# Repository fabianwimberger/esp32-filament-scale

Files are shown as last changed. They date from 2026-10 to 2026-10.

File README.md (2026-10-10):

# ESP32 Filament Scale




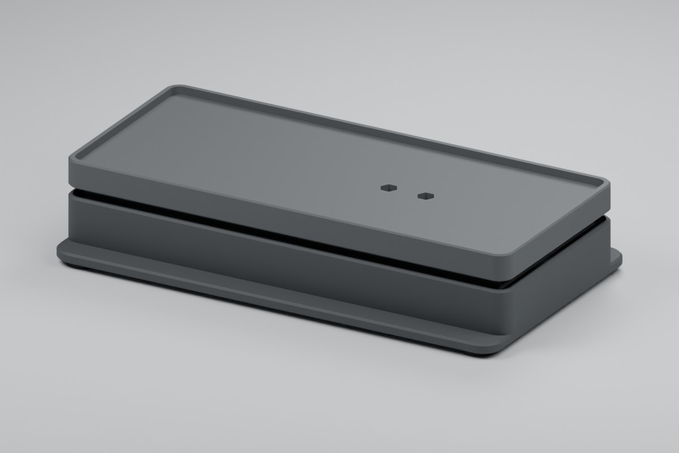
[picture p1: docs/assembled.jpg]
Assembled scale


Printed weighing plinth for a SUNLU S2 filament dryer. An ESP32-C3 and an HX711 report the filament left on the spool to Home Assistant through ESPHome.

## Background

A filament dryer hides the spool, so the only way to know whether a roll will last for the next print is to open the lid and guess. Weighing the whole dryer answers that without touching it: capture the weight once with a fresh spool inside, and everything that disappears afterwards is filament.

The scale is a 180 × 80 mm floating top on a 180 × 100 mm base, 34 mm tall, built around a cheap 5 kg bar load cell. It carries the S2's feet inside a low rim; the dryer's body overhangs it.

## Features

- **Filament remaining in grams and percent** — counts down from the mass of the spool you loaded
- **Calibration from Home Assistant** — three buttons: empty platform, known mass, dryer with full spool; no reflashing
- **Persistent calibration** — zero, gain and spool capture survive reboots and OTA updates; there is no startup tare
- **Stability gate** — a five-second window rejects captures while the reading moves and drops missing, stale or saturated samples
- **Four printed parts, M3 only** — base, top and two click-in board caps; four M3 × 20 screws clamp the cell
- **Parametric CAD** — one OpenSCAD file with assertions for every screw length and clearance
- **Diagnostics** — raw counts, noise range, saved calibration, chip temperature and Wi-Fi signal

## Quick Start

```bash
git clone https://github.com/fabianwimberger/esp32-filament-scale.git
cd esp32-filament-scale

python -m venv .venv
.venv/bin/pip install esphome

.venv/bin/esphome run firmware/scale.yaml   # first flash over USB
```

Join the **Filament Scale Setup** access point to enter your Wi-Fi, then add the discovered device in Home Assistant. Later updates go over the air:

```bash
.venv/bin/esphome run firmware/scale.yaml --device filament-scale.local
```

Print the four files in [`printable/`](printable/) and follow the [Build Guide](docs/build.md) for parts, wiring, assembly and calibration. The [Design Notes](docs/design.md) cover load path, clearances and limits.

To change the CAD:

```bash
make meshes   # export printable/*.stl from cad/scale.scad
make images   # re-render docs/ (OpenSCAD and Blender)
make check    # host tests, mesh checks, ESPHome config validation
```

## How It Works

```
dryer + spool ──► floating top ──► 5 kg bar cell ──► HX711 ──► ESP32-C3 ──► Home Assistant
                  (touches nothing    (fixed end        5 samples/s  5 s window    ESPHome API
                   but the cell)       on the base)

filament remaining = gross mass − (dryer + empty spool)
```

The cell is a cantilever: its cable end is clamped to a pedestal in the base, its free end to the top. Nothing else connects the two, so every gram on the top passes through the cell.

Calibration stores three values. **1 Capture empty platform** saves the zero, **2 Capture calibration mass** the counts per gram, and **3 Capture dryer with full spool** subtracts **Full filament mass** from the reading and saves the rest as dryer plus empty spool. Repeat step 3 for every new spool, because empty spools differ in weight.

Weight estimates use the median of the latest 25 samples to suppress brief filament pulls. Sustained load changes reach the estimate after about 2.6 seconds at the normal sample rate, then publish on the next five-second update. Zero and reference-mass captures still use the unfiltered average, and noise and stability diagnostics retain every sample. Updating this filter requires no recalibration and preserves the saved calibration and spool tare through a normal OTA update.

The design target is ±10 g. Cable tension, filament pull during a print, heat and plastic creep all shift the reading, so treat it as a trend while printing.

## Configuration

Substitutions at the top of `firmware/scale.yaml`:

| Variable | Default | Description |
|---|---|---|
| `device_name` | `filament-scale` | ESPHome node name / hostname |
| `friendly_name` | `Filament Scale` | Display name in Home Assistant |
| `dout_pin` | `GPIO4` | HX711 DT / DOUT |
| `clock_pin` | `GPIO3` | HX711 SCK / CLK |

The config ships without API encryption or an OTA password; add both before using it on a shared network.

Settings in Home Assistant:

| Entity | Default | Description |
|---|---|---|
| Full filament mass | 1000 g | Filament on the spool when step 3 is pressed |
| Calibration mass | 1000 g | Mass of the reference object used in step 2 |
| Calibration noise limit | 1000 counts | Largest raw range over five seconds that steps 1 and 2 accept |

Parameters at the top of `cad/scale.scad` adapt the print to other hardware:

| Variable | Default | Description |
|---|---|---|
| `platform_length`, `platform_width` | `180`, `80` | Top; the rim leaves 175 × 75 mm for the dryer's feet |
| `cell_hole_spacing`, `cell_hole_end` | `15`, `5` | Hole pattern of the 80 × 12.7 × 12.7 mm cell |
| `fixed_side` | `-1` | End of the cell that is clamped to the base |
| `esp32_pcb`, `hx711_pcb` | measured | Board sizes the pockets are cut for |
| `esp32_wire_zone` | `[3.6,14.4]` | Where the ESP32 cap is notched for wires, from the USB edge |

## License

MIT — see [LICENSE](LICENSE).

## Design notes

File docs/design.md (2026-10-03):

# Design Notes

Why the parts look the way they do, and what the design does not cover. Z positions are measured from the base floor and exclude the 2 mm pads.

## Load path

The dryer's feet stand on the top. A seat in the top's underside is clamped to the free end of the cell; the cable end of the cell is clamped to a pedestal in the base. That is the only connection between the two parts.

The load tips the pedestal towards the free end: its front edge presses down and its rear screw pulls up with about three times the load each, 19 mm apart. Two solid rails run beside the cell from behind the pedestal to the far end wall and spread that couple over 140 mm. Nothing stands under the cell, which has to bend freely.

## Clearances

| Clearance | Nominal |
|---|---:|
| Top above the base wall (the visible gap) | 3.5 mm |
| Top's underside inside the base walls | 4 mm |
| Top's underside above the base rails | 4 mm |
| Top's underside above the board caps | 6.9 mm |
| Cell above the base floor | 2.3 mm, 1.3 mm at the potting |
| Channel roof above the fixed-end screw tips | 4.2 mm |

Assertions in [`cad/scale.scad`](../cad/scale.scad) fail the export if a parameter change breaks one of these.

## Fastening

The cell's M4 and M5 threads are larger than M3, so every screw passes through the cell and clamps it with a nut.

- **Fixed end** — heads in counterbores under the base, 3.7 mm of printed seat, the cell, then washer and nut. The seat is as thick as a 20 mm screw allows, which leaves the heads 0.4 mm proud of the floor, inside the height of the pads.
- **Moving end** — head and washer under the cell, through the cell and 3.6 mm of solid seat into a nut at the bottom of a hex well open to the top face. The nut has to sit above the seat: a nut between seat and cell would be drawn onto the cell and leave the top loose.

The screws have about 1 mm of play in the cell's holes. Lips on the pedestal form a 13 mm slot that sets the cell's angle; the top's seat is flat and is squared by eye before tightening.

## Stiffness

The top is carried from one 24 mm seat and cantilevers about 105 mm past it. It is a 7.5 mm plate on a solid underside 5.5 mm deep that hangs inside the base and ends level with the top of the cell, with a channel over the cell. At this depth a solid section is the stiffest option: ribs would sag about twice as much.

A beam estimate with E = 1.5 GPa puts the sag at the far feet at about 0.15 mm under 2 kg printed solid and 0.2 mm at 50% infill, plus about 0.2 mm from the base. Sag does not change the reading, since all weight still passes through the cell. An earlier 3.75 mm plate on a 4.5 mm underside sagged four times as much and visibly wobbled.

## Dimensions

| Feature | Position |
|---|---|
| Base | 180 × 100 mm footing, Z 0–4; 180 × 80 mm shell with 1.6 mm walls to Z 21 |
| Pedestal | X −40 to −16, top at Z 6.3, lips to Z 7.3 |
| Rails | 6 mm wide beside the cell; Z 15 at the pedestal, tapering to Z 8 at the far wall |
| Cell | Z 6.3–19, screws at X ±20 and ±35 |
| Board pockets | Boards at Z 5, walls to Z 10.5, caps to Z 12.1 |
| USB notch | X −73 to −57 in the rear wall, above Z 4.5 |
| Top | Plate Z 24.5–32, rim to Z 35, underside 168.8 × 68.8 mm down to Z 19 |
| Pads | X ±80, Y ±42 |

The caps limit how far a board can lift (0.5 to 1.7 mm) instead of clamping it, so they tolerate parts of different height. Each leg is 1 mm thick and bends 0.55 mm over a 0.7 mm ridge, about 3% strain.

## Limits

- **No overload stops.** The top would have to close the full 3.5 mm gap before the base catches it, far beyond the roughly 150% a 5 kg cell survives.
- **Off-center load.** The feet load the cell eccentrically. A bar cell's rating says nothing about corner accuracy; the checks in the [Build Guide](build.md#7-verify) measure it.
- **Heat.** The electronics sit in the same enclosure as the cell, under a dryer. The gap, the floor openings and the USB notch let air through, but the cell's temperature under a long drying cycle has not been measured.
- **Creep.** Printed seats relax under clamp force and warmth. Long-term drift has not been quantified.
- **Tipping.** The pads sit at Y ±42 against ±35 for the dryer's own feet, which roughly makes up for standing 34 mm higher.
- **Not sealed.** The enclosure is open to dust and spills.

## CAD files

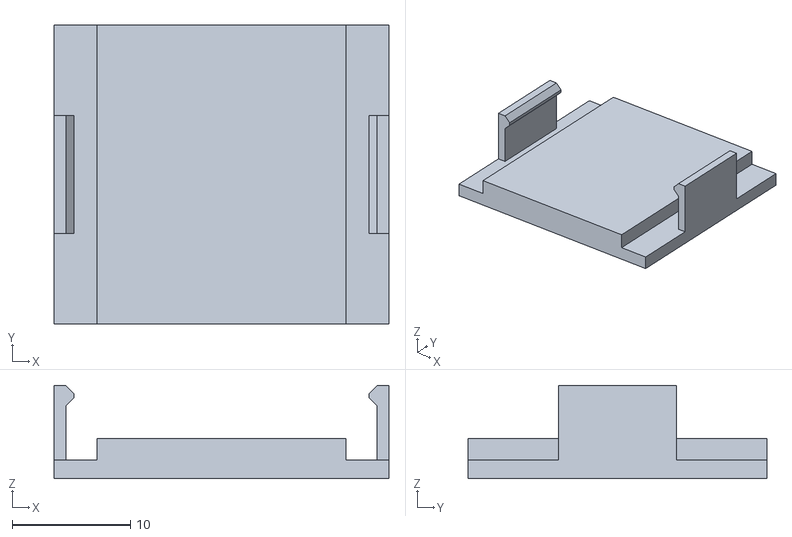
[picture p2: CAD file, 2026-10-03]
printable/hx711_cap.stl
28.4 x 25.4 x 7.90

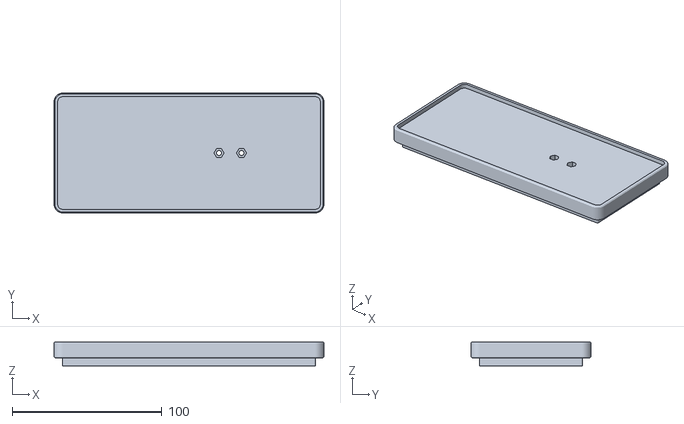
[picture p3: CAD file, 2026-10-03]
printable/deck.stl
180.0 x 80.0 x 16.0

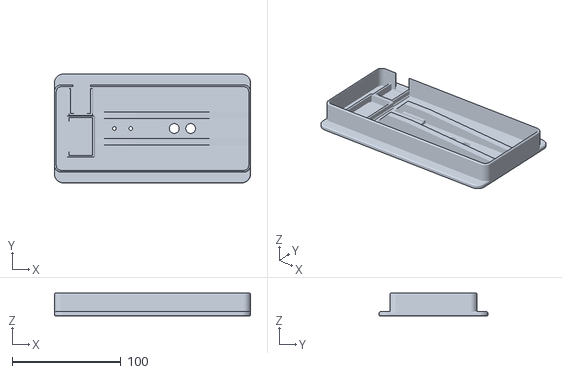
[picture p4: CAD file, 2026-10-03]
printable/base.stl
180.0 x 100.0 x 21.0

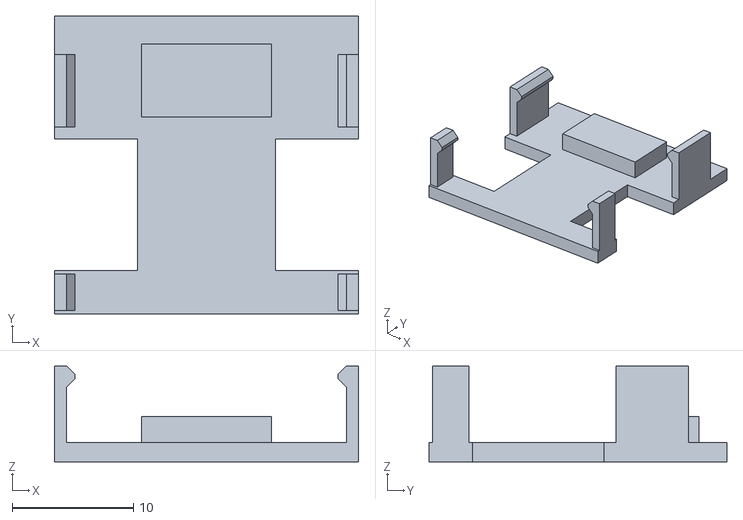
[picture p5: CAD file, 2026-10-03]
printable/esp32_cap.stl
25.1 x 24.5 x 7.90

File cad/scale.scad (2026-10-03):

// Weighing plinth for a filament dryer on an 80 mm bar load cell. Millimetres.
// M3 screws pass through the cell's M4/M5 threads and clamp with nuts,
// so either end of the cell can be the fixed one.
part = "assembly";
platform_length = 180;
platform_width = 80;
// A footing 10 mm wider on each side resists tipping; it stays below the shadow line.
base_width = 100;
floor_height = 4;
wall = 1.6;
shell_height = 21;
cell_length = 80;
cell_width = 12.7;
cell_height = 12.7;
cell_hole_end = 5;
cell_hole_spacing = 15;
// Lips beside the pedestal pad hold the cell straight and centered; the screws only clamp.
cell_slot = 13;
lip_height = 1;
// Potting over the strain gauges stands proud of the top and bottom faces.
cell_potting = 1;
// The fixed end is the cable end, on the side of the boards (-1 = left).
fixed_side = -1;
deck_bottom = 24.5;
deck_height = 7.5;
// A low rim around the top keeps the dryer's feet (168 x 70 mm outer) from walking off.
rim_width = 2.4;
rim_height = 3;
// Solid underside inside the shell: the stiffest shape for its depth, and it prints flat on the bed.
// It ends level with the cell top, so the cell seat is part of the first printed layer.
under_depth = 5.5;
under_gap = 4;
channel_gap = 2;
// The channel over the cell runs this far past the fixed cell end and rises this far into the plate.
channel_overrun = 4;
channel_rise = 2.3;
fixed_screw = 20;
moving_screw = 20;
foot_height = 2;
explode = 0;
show_electronics = true;
// Measured ESP32-C3 board: PCB, then a USB-C connector on a short edge.
esp32_pcb = [17.75,22.75,1.67];
esp32_usb_length = 1.75;
esp32_usb_height = 4.82;
esp32_usb_width = 8.5;
esp32_x = -66;
esp32_base_z = floor_height+1;
// The connector tip meets the inner rear wall so a cable engages through the notch.
esp32_usb_tip_y = platform_width/2-wall;
esp32_back_y = esp32_usb_tip_y-esp32_usb_length-esp32_pcb[1];
notch_x = -73;
notch_width = 16;
notch_z = 4.5;
// Pockets hold both boards 1 mm above the floor with a slip fit; wires leave from the top.
board_clear = 0.3;
cradle_wall = 1.5;
cradle_top = esp32_base_z+5.5;
// Caps click over the long pocket walls: a hook on each leg passes a ridge near the foot of the wall.
cap_plate = 1.6;
snap = 0.7;
snap_z = floor_height+1.2;
leg_gap = 0.15;
leg_thick = 1;
// ESP32 wires rise along a long edge, this far from the USB edge (G to GPIO3); the cap is notched there.
esp32_wire_zone = [3.6,14.4];
esp32_wire_inset = 3.2;
// The HX711 pad rows and their wires stay uncovered at both short ends.
hx711_wire_zone = 4.5;
hx711_height = 3.22;
// Rails beside the cell stiffen the base in the direction the load tips the pedestal.
rail_top = 15;
rail_width = 6;
rail_end = 8;
// Measured HX711 breakout, long side front to back, pad rows on both short ends.
// It sits directly in front of the ESP32, 0.5 mm between the pocket walls.
hx711_pcb = [21.06,34.35];
hx711_center = [esp32_x,esp32_back_y-2*(board_clear+cradle_wall)-0.5-hx711_pcb[1]/2];
$fn = 64;

m3_clear = 3.4;
m3_nut = 5.8/cos(30);
nut_height = 2.4;
washer_od = 8;
washer_height = 1;
head_height = 3;
cell_top = deck_bottom-under_depth;
cell_bottom = cell_top-cell_height;
// The channel over the cell has vertical walls to this far below the plate, then 45 degree flanks on all four sides.
channel_flank = under_depth-cell_potting-0.5;
// Fixed end: heads in counterbores under the base, nuts on top of the cell. The seat between head
// and cell is as thick as a 20 mm screw allows, so the heads stand slightly proud of the floor.
fixed_seat = 3.7;
head_bore = cell_bottom-fixed_seat;
fixed_tip = head_bore+fixed_screw;
// Moving end: the nut bears on this much solid seat, in a hex well open to the top.
nut_seat = 3.6;
moving_reach = moving_screw-washer_height-cell_height;
// Clamp pads cover both holes plus washer margin and stay clear of the strain-gauge zone.
mount_length = cell_hole_end+cell_hole_spacing+4;
mount_center = cell_length/2-mount_length/2;
pad_y = base_width/2-8;
assert(base_width >= platform_width && platform_length >= 180);
// The sagging deck must never press on the potting and bypass the cell.
assert(under_depth-cell_potting >= 1.5 && deck_bottom-shell_height >= 2);
assert(cell_slot-cell_width >= 0.2 && cell_slot <= cell_width+2);
// Fixed end: seat, cell and washer, through the nut on top.
assert(fixed_seat >= 3 && fixed_seat+cell_height+washer_height+nut_height <= fixed_screw);
assert(head_height-head_bore <= foot_height-1);
// Moving end: washer, cell and seat, fully through the nut and ending below the top surface.
assert(moving_reach >= nut_seat+nut_height && moving_reach <= under_depth+deck_height-0.5);
// The underside passes over the capped boards, their wires and the base rails.
assert(cell_top >= cradle_top+cap_plate+4 && cell_top >= rail_top+4);
// The caps clear the USB connector and the tallest HX711 part; the legs bend less than PETG tolerates.
assert(esp32_base_z+esp32_usb_height <= cradle_top-0.5 && esp32_base_z+hx711_height <= cradle_top-1.5);
assert(1.5*leg_thick*(snap-leg_gap)/pow(cradle_top-snap_z,2) <= 0.04);
// The channel flanks stay 1.5 mm clear of the potting on top of the cell and of the fixed-end nuts.
assert((channel_gap+under_depth-cell_potting-channel_flank)/sqrt(2) >= 1.5);
assert((cell_width/2+channel_gap+under_depth-channel_flank-m3_nut/2-washer_height-nut_height)/sqrt(2) >= 1.5);
assert((channel_overrun+cell_hole_end-m3_nut/2+under_depth-channel_flank-washer_height-nut_height)/sqrt(2) >= 1.5);
// The channel roof is wider than the screws, 3 mm above their tips, and leaves a solid plate above.
assert(cell_width/2+channel_gap-channel_flank-channel_rise >= 2 && deck_bottom+channel_rise-fixed_tip >= 3);
assert(deck_height-channel_rise >= 4);
assert(platform_length-2*rim_width >= 168+4 && platform_width-2*rim_width >= 70+4);
// The board envelope and its USB connector stay clear of the shell and inside the notch.
assert(esp32_base_z+esp32_pcb[2] <= shell_height);
assert(esp32_x-esp32_pcb[0]/2 >= -(platform_length/2-wall));
assert(esp32_x+esp32_pcb[0]/2 <= platform_length/2-wall);
assert(esp32_usb_tip_y <= platform_width/2-wall+0.001);
assert(esp32_x-esp32_usb_width/2 >= notch_x);
assert(esp32_x+esp32_usb_width/2 <= notch_x+notch_width);
// A USB-C plug body (about 6.5 mm tall) centred on the connector clears the notch floor and footing.
assert(notch_z > floor_height && notch_z <= esp32_base_z+(esp32_pcb[2]+esp32_usb_height)/2-3.5);
// The HX711 pocket stays clear of the fixed pedestal and the front wall.
assert(fixed_side == -1 && hx711_center[0]+hx711_pcb[0]/2+board_clear+cradle_wall <= -cell_length/2-5);
assert(hx711_center[1]-hx711_pcb[1]/2-board_clear-cradle_wall >= -(platform_width/2-wall)+2);

module outline(l,w,h,r=6) {
    linear_extrude(h) hull()
        for(x=[-l/2+r,l/2-r]) for(y=[-w/2+r,w/2-r])
            translate([x,y]) circle(r=r);
}

module soft_plate(l,w,h,r=6,bevel=0.8) {
    hull() {
        translate([0,0,bevel]) outline(l,w,h-2*bevel,r);
        outline(l-2*bevel,w-2*bevel,h,r-bevel);
    }
}

// Square-cornered, so the lips and the pedestal merge flush with the rails beside them.
module locating_lips(h) {
    for(y=[-cell_width/2-3,cell_slot/2])
        translate([-mount_length/2,y,0]) cube([mount_length,cell_width/2+3-cell_slot/2,h]);
}

module bore(x,y,d,z,h) {
    translate([x,y,z]) cylinder(d=d,h=h);
}

module hole_positions(side) {
    for(offset=[cell_hole_end,cell_hole_end+cell_hole_spacing])
        translate([side*(cell_length/2-offset),0,0]) children();
}

// Prism along +Y from the origin with the given [x,z] cross-section.
module prism_y(length,points) {
    translate([0,length,0]) rotate([90,0,0]) linear_extrude(length) polygon(points);
}

// Ridge on a wall face at X = 0 that faces +X; both flanks at 45 degrees.
module snap_ridge(length) {
    prism_y(length,[[-0.1,snap_z-0.1],[snap,snap_z+snap],[-0.1,snap_z+2*snap+0.1]]);
}

// Cap leg outside a wall face at X = 0 that faces +X; its hook sits under the ridge.
module snap_leg(width) {
    a = snap+leg_gap;
    b = a+leg_thick;
    zb = floor_height+0.2;
    zc = snap_z-0.1+leg_gap;
    prism_y(width,[[a,cradle_top+0.01],[b,cradle_top+0.01],[b,zb],[a,zb],
                   [leg_gap,zb+snap],[leg_gap,zc],[a,zc+snap]]);
}

// Children are placed on both long walls of a pocket whose outer faces are at x0 and x1.
module both_walls(x0,x1) {
    translate([x1,0,0]) children();
    translate([x0,0,0]) mirror([1,0,0]) children();
}
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

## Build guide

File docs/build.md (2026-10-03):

# Build Guide

Parts, wiring, printing, assembly and calibration. The reasoning behind the dimensions is in the [Design Notes](design.md).

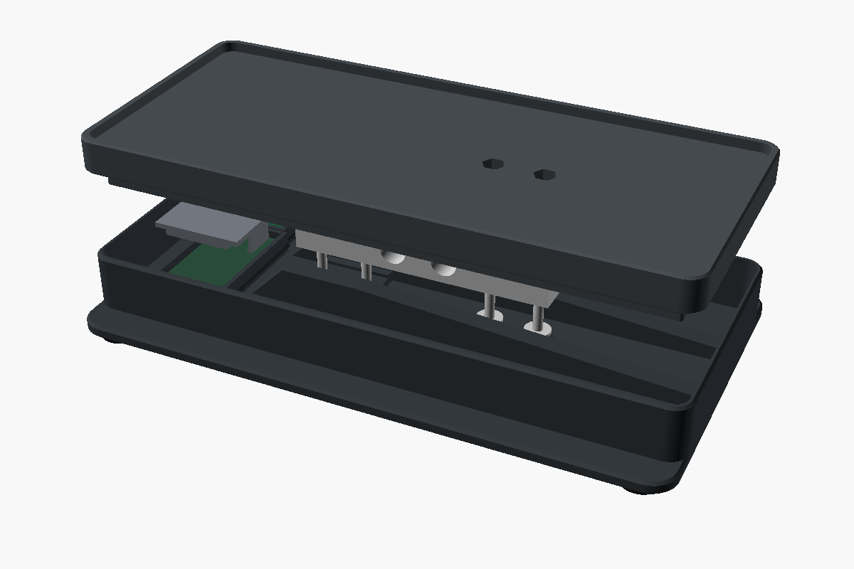
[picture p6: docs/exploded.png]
Exploded assembly


## 1. Parts

| Qty | Part | Notes |
|---:|---|---|
| 1 | ESP32-C3 "super mini" board | 22.75 × 17.75 mm PCB, USB-C on a short edge, no pin headers |
| 1 | Bar load cell, 5 kg | 80 × 12.7 × 12.7 mm, four wires, two M4 and two M5 through-holes 15 mm apart, outer holes 5 mm from the ends |
| 1 | HX711 breakout | 34.35 × 21.06 mm, pad rows on both short ends |
| 4 | M3 × 20 socket head screws | ISO 4762 / DIN 912 |
| 4 | M3 nuts | |
| 4 | M3 washers, 8 mm OD | Up to 1 mm thick; required, the cell's holes leave an M3 head almost no bearing face |
| 4 | Rubber pads | 12 mm diameter, 2 mm thick, adhesive |
| 1 | USB-C cable and 5 V supply | |
| 1 | Known mass, about 1 kg | For calibration |

Check the cell before printing: 12.7 mm tall, through-holes, 15 mm hole spacing, and the potting over the strain gauges no more than 1 mm proud. Boards sold under the same name vary in size; compare yours with `esp32_pcb` and `hx711_pcb` in [`cad/scale.scad`](../cad/scale.scad). The 55 mm TAL220B and three-wire bathroom-scale sensors do not fit.

## 2. Print

| File | Orientation | Supports |
|---|---|---|
| `base.stl` | Floor down | None |
| `deck.stl` | Top up, flat on its underside | Under the 5.6 mm plate edge only, from the build plate |
| `esp32_cap.stl` | Top face down, legs up | None |
| `hx711_cap.stl` | Top face down, legs up | None |

All four files are exported in print orientation. PETG, six walls, six top and bottom layers, 50% gyroid infill. Print the cell pedestal in the base and the cell seat in the deck solid; a fully solid deck is about 40% stiffer.

After printing, check that an M3 nut drops to the bottom of both hex wells in the top face and that each cap clicks onto its empty pocket and pulls off again.

## 3. Wire

Solder the wires to the top of each board and trim anything that pokes through underneath.

| From | To |
|---|---|
| ESP32 3V3 | HX711 VCC |
| ESP32 GND | HX711 GND |
| ESP32 GPIO4 | HX711 DT |
| ESP32 GPIO3 | HX711 SCK |
| Cell red | HX711 E+ |
| Cell black | HX711 E− |
| Cell green | HX711 A+ |
| Cell white | HX711 A− |

Power a single-supply HX711 board from **3V3, never 5 V**: at 5 V its data line drives 5 V into the ESP32. A board with separate VCC and VDD pins takes 5 V on VCC and 3V3 on VDD. Cell wire colors vary; confirm them against your cell's drawing.

The ESP32 cap is notched for wires on the second to fifth pin from the USB edge (GND, 3V3, GPIO4, GPIO3 on the measured board). Change `esp32_wire_zone` if yours differ.

## 4. Assemble

1. Stick the four rubber pads under the corners of the base. They keep the screw heads and the two floor openings clear of the table.
2. Push an M3 × 20 up through each counterbore under the pedestal.
3. Lower the cell over the two screws, cable end into the slot between the pedestal lips, cable towards the boards. Which face is up does not matter.
4. Put a washer and a nut on each screw on top of the cell and tighten, holding the head with a hex key from below.
5. Drop the ESP32-C3 into the rear pocket with its USB-C connector in the wall notch, and the HX711 into the pocket in front of it with DT/SCK towards the ESP32. Lead the wires straight up and click both caps on.
6. Keep every wire at least 3 mm below the top of the cell and never route one over it. Leave a relaxed loop where the cable leaves the cell.
7. Lower the top onto the free end of the cell and drop a nut into each hex well.
8. From below, through the two floor openings, insert an M3 × 20 with a washer into each hole and tighten it into the nut. Before the last turn, square the top to the base so the gap is even all round; only clamp friction holds that angle.

Tighten moderately: the cell is aluminium and the seats are printed. Retighten after the first day under load.

The top must float. Check the 3.5 mm gap between top and base all round, with the dryer and the heaviest spool on it, and never fill it with foam or tape. If the top touches the base, a wire or a board, the reading is wrong.

There are no overload stops. Do not lean on the top, and lift the scale by its base. Keep the total load below 4 kg.

## 5. Flash

1. Connect the board over USB and run `esphome run firmware/scale.yaml`.
2. Join **Filament Scale Setup**, enter your Wi-Fi in the captive portal, and add the discovered ESPHome device in Home Assistant.
3. Press on the top and confirm that **Raw counts** changes within a few seconds.

To use an existing ESPHome installation instead, copy `scale.yaml` and `readings.h` together.

## 6. Calibrate

Let the scale warm up for ten minutes with its cables in their final routing. Wait ten seconds after each load change. Every button answers through **Setup message**.

1. Clear the top and press **1 Capture empty platform**.
2. Set **Calibration mass** to the mass of your reference object, put it on the center of the top and press **2 Capture calibration mass**.
3. Remove the reference. **Gross mass** should return to about zero.
4. Put the dryer on the top with a full spool inside, lid closed, cables routed as in use.
5. Set **Full filament mass** to the filament on that spool: 1000 g for a new 1 kg roll, or what is left on a used one.
6. Press **3 Capture dryer with full spool**. Wait 15 seconds before removing power so the values are saved.

Repeat steps 4 to 6 for every new spool. Steps 1 and 2 only need repeating after a mechanical change.

A rejected capture means the reading was still moving. **Raw noise range** shows by how much; find the cause before raising **Calibration noise limit**.

**Calibration zero** and **Calibration counts per gram** publish the saved values. Note them: they are lost if the flash is erased.

## 7. Verify

| Check | Procedure | Target |
|---|---|---|
| Repeatability | Remove and replace a known 1 kg mass five times | Within ±10 g |
| Off-center load | Same mass at the center and near each dryer foot | Within ±10 g, top never touches the base |
| Cables | Move the slack in the dryer's power cable and the filament path | No lasting shift above 10 g |
| Heat | Same load cold, after 30 and 120 minutes of drying, and cooled down | Note the drift; set alerts wider than it |
| Reboot | Power-cycle with a partly used spool installed | Same estimate, no tare |

The cell is temperature-compensated up to 40 °C and rated to 55 °C. **Electronics temperature** is the ESP32's die temperature, not the cell's.

While a print pulls on the filament the estimate moves with it. Read it when **Reading stable** is on.

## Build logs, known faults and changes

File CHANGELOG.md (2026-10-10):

# Changelog

All notable changes to this project are documented in this file.

The format is based on [Keep a Changelog](https://keepachangelog.com/en/1.1.0/),
and this project adheres to [Semantic Versioning](https://semver.org/spec/v2.0.0.html).

## [v1.0.1] - 2026-10-03

This patch suppresses brief filament-pull spikes in weight estimates while preserving saved calibration and spool tare.

### Fixes

- Use the median of the latest 25 samples so brief disturbances do not pull down the reported filament remaining.
- Continue tracking sustained load changes and gradual consumption while retaining all samples for zero and reference-mass captures, noise measurements, and stability checks.
- Preserve calibration, spool tare, settings, and entities through a normal OTA update; no recalibration is required.

### Documentation & Links

- [Build and calibration guide](https://github.com/fabianwimberger/esp32-filament-scale/blob/v1.0.1/docs/build.md)
- [Filtering and configuration](https://github.com/fabianwimberger/esp32-filament-scale/blob/v1.0.1/README.md)
- [ESP32-C3 OTA firmware](https://github.com/fabianwimberger/esp32-filament-scale/releases/download/v1.0.1/firmware.ota.bin), built with ESPHome 2026.9.1. Use this image for OTA updates to retain saved settings.

## [v1.0.0] - 2026-10-03

First release of the printed filament scale for the SUNLU S2 dryer: CAD, printable parts and ESPHome firmware.

### Features

- Report filament remaining in grams and percent to Home Assistant, counting down from the spool that was loaded
- Calibrate from Home Assistant with three buttons: empty platform, known mass, dryer with full spool
- Keep zero, gain and spool capture across reboots and OTA updates, with no startup tare
- Reject captures while the reading moves, and drop missing, stale or saturated samples
- Four printed parts in print orientation: base, top and two click-in board caps, held together by four M3 × 20 screws
- Parametric OpenSCAD source with assertions for every screw length and clearance
- Diagnostic sensors for raw counts, noise range, saved calibration, chip temperature and Wi-Fi signal

### Testing

- Run the readings test, the mesh checks and ESPHome config validation on pull requests and pushes to main and develop
- Compile the ESP32-C3 firmware in CI with ESPHome 2026.9.1

### Documentation & Links

- Repository: https://github.com/fabianwimberger/esp32-filament-scale
- Build guide: [docs/build.md](https://github.com/fabianwimberger/esp32-filament-scale/blob/main/docs/build.md)
- Design notes: [docs/design.md](https://github.com/fabianwimberger/esp32-filament-scale/blob/main/docs/design.md)

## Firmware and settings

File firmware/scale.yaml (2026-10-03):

substitutions:
  device_name: filament-scale
  friendly_name: Filament Scale
  dout_pin: GPIO4
  clock_pin: GPIO3

esphome:
  name: ${device_name}
  friendly_name: ${friendly_name}
  includes:
    - readings.h

esp32:
  variant: esp32c3
  flash_size: 4MB
  framework:
    type: esp-idf

logger:
  # Five samples and several published values per second would bury everything else.
  logs:
    hx711: INFO
    sensor: INFO

api:

ota:
  - platform: esphome

wifi:
  ap:
    ssid: Filament Scale Setup
captive_portal:

preferences:
  flash_write_interval: 10s

globals:
  - id: zero_counts
    type: float
    restore_value: true
    initial_value: '0'
  - id: counts_per_g
    type: float
    restore_value: true
    initial_value: '0'
  - id: zero_set
    type: bool
    restore_value: true
    initial_value: 'false'
  - id: dryer_tare_g
    type: float
    restore_value: true
    initial_value: '0'
  - id: tare_set
    type: bool
    restore_value: true
    initial_value: 'false'

number:
  - platform: template
    name: Full filament mass
    id: full_g
    unit_of_measurement: g
    min_value: 100
    max_value: 2000
    step: 1
    initial_value: 1000
    optimistic: true
    restore_value: true
    mode: box
  - platform: template
    name: Calibration mass
    id: reference_g
    entity_category: config
    unit_of_measurement: g
    min_value: 100
    max_value: 3000
    step: 1
    initial_value: 1000
    optimistic: true
    restore_value: true
    mode: box
  - platform: template
    name: Calibration noise limit
    id: noise_limit
    entity_category: config
    min_value: 50
    max_value: 10000
    step: 50
    initial_value: 1000
    optimistic: true
    restore_value: true
    mode: box

sensor:
  - platform: hx711
    id: raw_counts
    name: Raw counts
    entity_category: diagnostic
    dout_pin: ${dout_pin}
    clk_pin: ${clock_pin}
    gain: 128
    update_interval: 200ms
    accuracy_decimals: 0
    # The stability window sees every sample; Home Assistant receives one value every 5 s.
    on_raw_value:
      then:
        - lambda: filament_scale::samples.add(x, millis());
    filters:
      - throttle_average: 5s
  - platform: template
    name: Gross mass
    id: gross_g
    unit_of_measurement: g
    device_class: weight
    state_class: measurement
    accuracy_decimals: 0
    update_interval: 5s
    lambda: return filament_scale::samples.mass(millis(), id(zero_counts), id(counts_per_g));
  - platform: template
    name: Filament remaining
    id: remaining_g
    unit_of_measurement: g
    device_class: weight
    state_class: measurement
    accuracy_decimals: 0
    update_interval: 5s
    lambda: |-
      if (!id(tare_set)) return NAN;
      float gross = filament_scale::samples.mass(millis(), id(zero_counts), id(counts_per_g));
      if (!std::isfinite(gross) || gross < id(dryer_tare_g) - 50) return NAN;
      return std::max(0.0f, gross - id(dryer_tare_g));
  - platform: template
    name: Filament remaining percent
    unit_of_measurement: '%'
    state_class: measurement
    accuracy_decimals: 1
    update_interval: 5s
    lambda: |-
      if (!id(tare_set)) return NAN;
      float gross = filament_scale::samples.mass(millis(), id(zero_counts), id(counts_per_g));
      if (!std::isfinite(gross) || gross < id(dryer_tare_g) - 50) return NAN;
      return std::min(100.0f, std::max(0.0f, 100.0f * (gross - id(dryer_tare_g)) / id(full_g).state));
  - platform: template
    name: Raw noise range
    entity_category: diagnostic
    # A state class makes Home Assistant treat it as a number and keeps it out of the logbook.
    state_class: measurement
    accuracy_decimals: 0
    update_interval: 5s
    lambda: |-
      return filament_scale::samples.ready(millis()) ? filament_scale::samples.range() : NAN;
  - platform: template
    name: Saved dryer and empty spool
    entity_category: diagnostic
    unit_of_measurement: g
    accuracy_decimals: 0
    update_interval: 60s
    lambda: |-
      return id(tare_set) ? id(dryer_tare_g) : NAN;
  - platform: internal_temperature
    name: Electronics temperature
    entity_category: diagnostic
    update_interval: 60s
  - platform: wifi_signal
    name: WiFi signal
    update_interval: 60s
  # The saved calibration, so it can be read back and re-entered if the flash is ever erased.
  - platform: template
    name: Calibration zero
    entity_category: diagnostic
    state_class: measurement
    accuracy_decimals: 0
    update_interval: 60s
    lambda: |-
      return id(zero_set) ? id(zero_counts) : NAN;
  - platform: template
    name: Calibration counts per gram
    entity_category: diagnostic
    state_class: measurement
    accuracy_decimals: 3
    update_interval: 60s
    lambda: |-
      return std::abs(id(counts_per_g)) >= 0.001f ? id(counts_per_g) : NAN;
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

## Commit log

2026-10-03 ci: align branch filters with other repositories
2026-10-03 fix: suppress brief filament-pull weight spikes
